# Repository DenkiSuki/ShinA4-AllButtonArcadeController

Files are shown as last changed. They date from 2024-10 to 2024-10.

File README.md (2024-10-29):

# ShinA4-AllButtonArcadeController
Repo for ShinA4, a custom 3DPrinted All Button Arcade Controller
ShinA4Hitbox-Layout
ShinA4Hitbox-2

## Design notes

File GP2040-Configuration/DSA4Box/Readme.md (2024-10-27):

# GP2040 Configuration for DSA4Box
3DPrinted Waveshare RP2040-Zero Based Arcade Controller
14+6Buttons
14RGBs LED for directional and action button 
USB Host
OLED

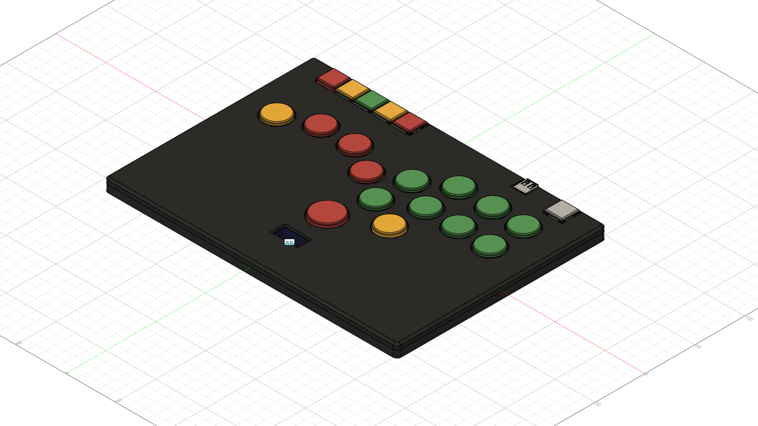
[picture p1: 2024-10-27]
Picture/ShinA4Hitbox-2.png

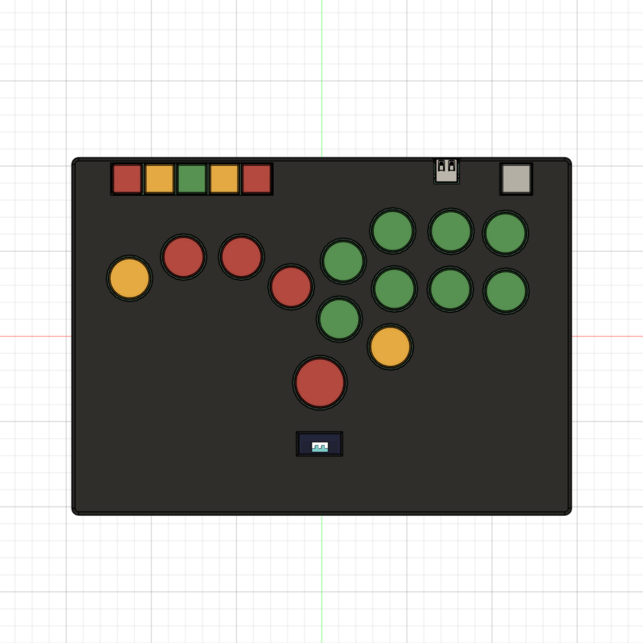
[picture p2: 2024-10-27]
Picture/ShinA4Hitbox-1.png

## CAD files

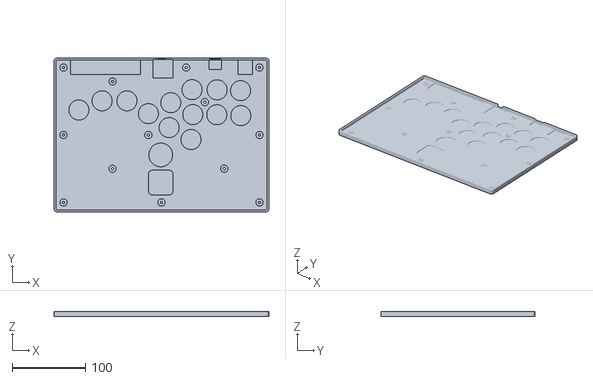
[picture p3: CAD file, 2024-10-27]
3DFile/BottomCase.stl
293.4 x 210.0 x 7.00

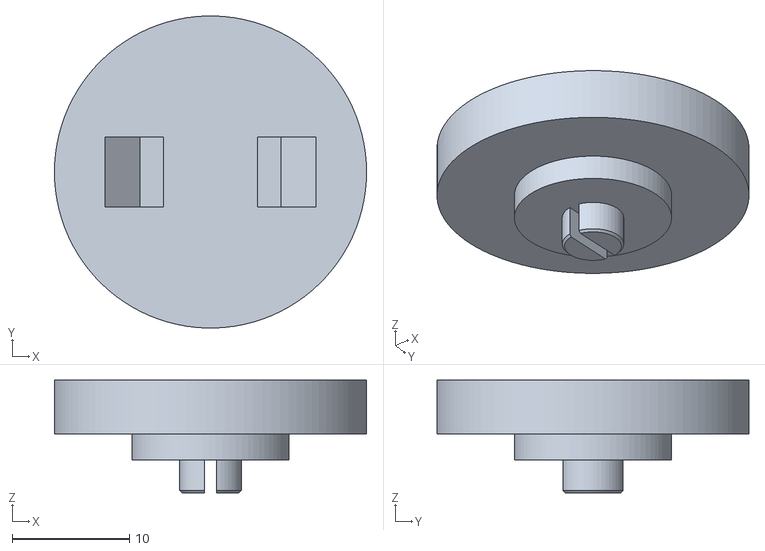
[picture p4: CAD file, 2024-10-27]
3DFile/HoleCap.stl
26.6 x 26.6 x 9.60

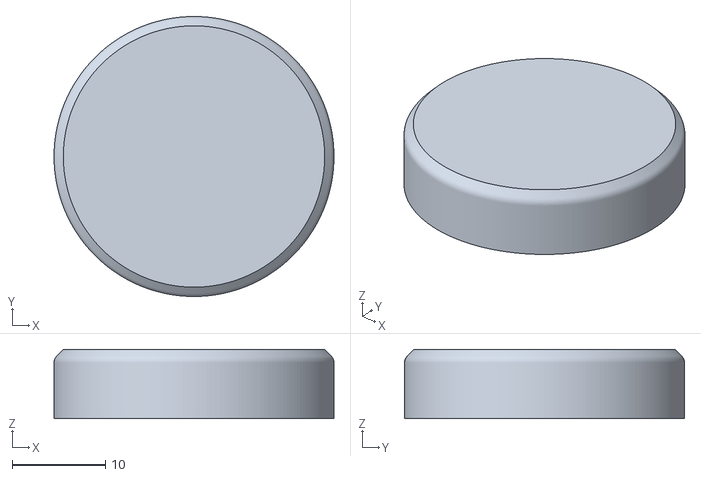
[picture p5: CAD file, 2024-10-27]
3DFile/30mmButtonCap.stl
30.0 x 30.0 x 7.40

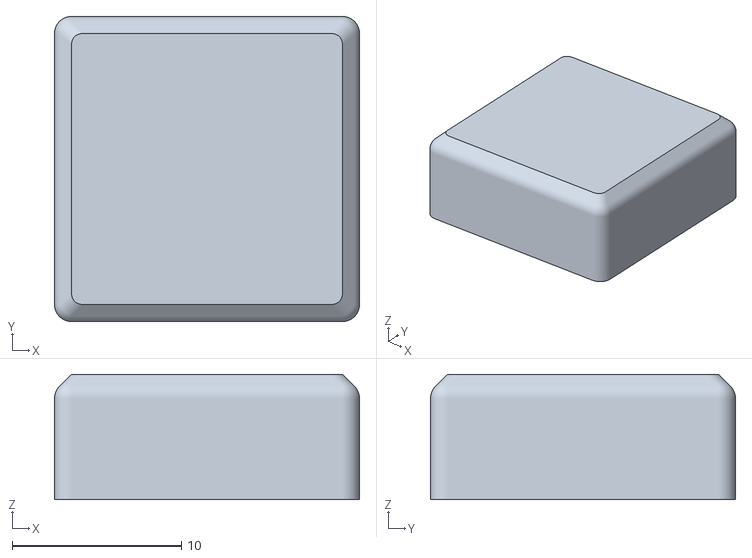
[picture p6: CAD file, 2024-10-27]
3DFile/MenuButtonCap.stl
18.0 x 18.0 x 7.40

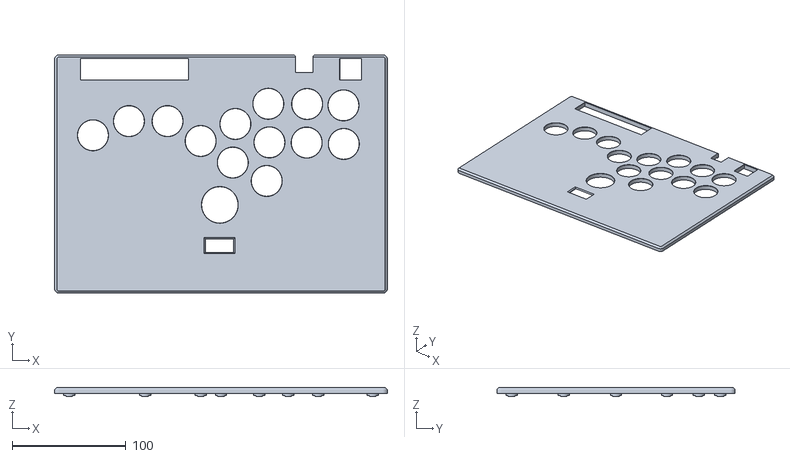
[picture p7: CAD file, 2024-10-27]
3DFile/TopCase.stl
293.4 x 210.0 x 8.20

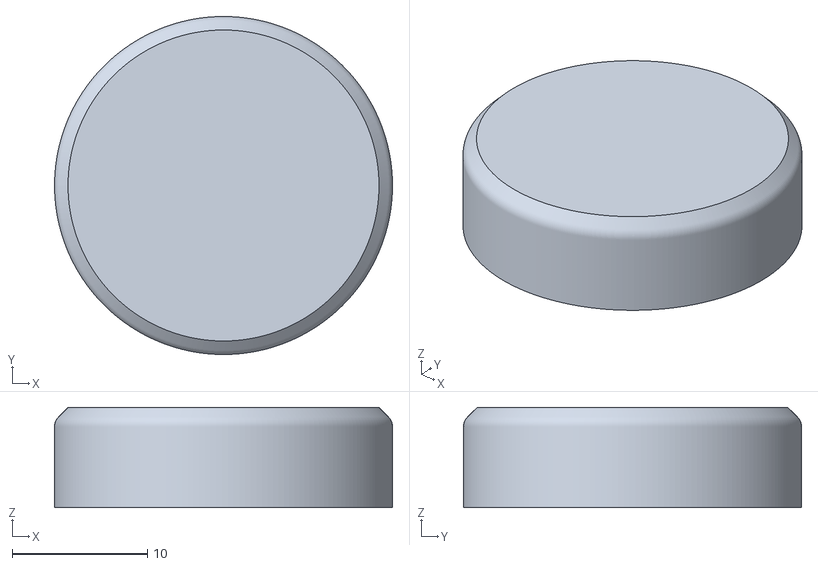
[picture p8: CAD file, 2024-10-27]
3DFile/25mmButtonCap.stl
25.0 x 25.0 x 7.40

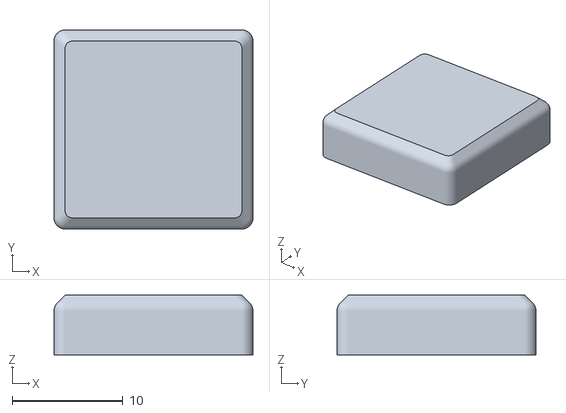
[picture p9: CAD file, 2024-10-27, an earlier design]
3DFile/Legacy/MenuButtonCap.stl
18.0 x 18.0 x 5.40

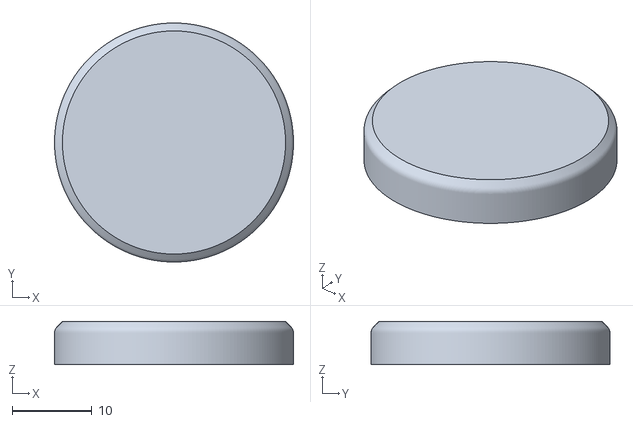
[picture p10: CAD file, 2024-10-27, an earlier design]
3DFile/Legacy/30mmButtonCap.stl
30.0 x 30.0 x 5.40

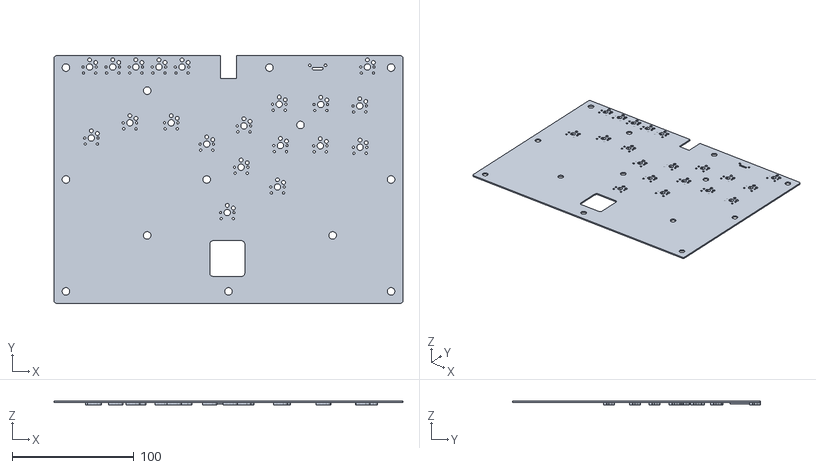
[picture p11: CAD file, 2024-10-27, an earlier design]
3DFile/Legacy/PseudoPCB.stl
287.0 x 203.6 x 3.40

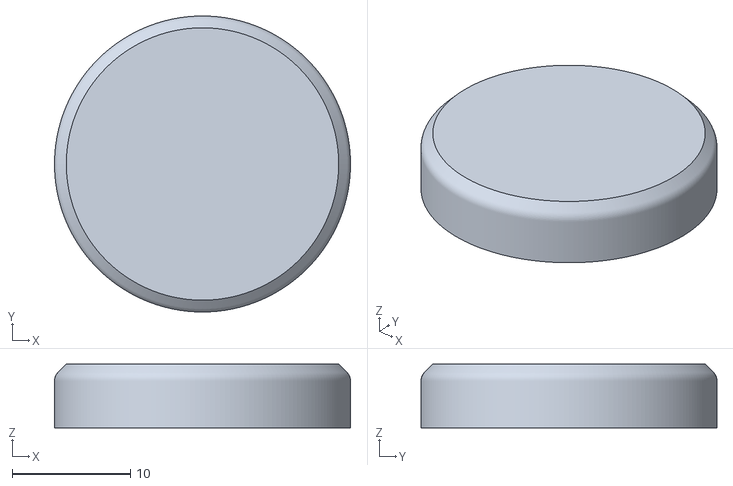
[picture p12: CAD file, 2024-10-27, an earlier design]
3DFile/Legacy/25mmButtonCap.stl
25.0 x 25.0 x 5.40

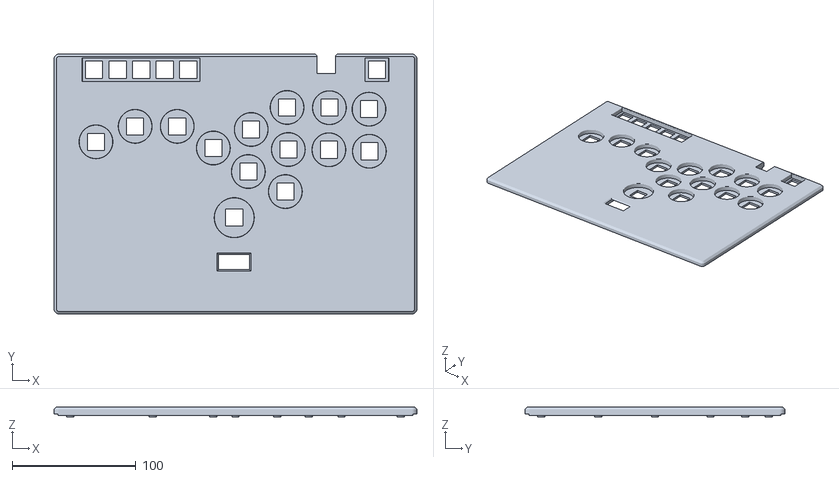
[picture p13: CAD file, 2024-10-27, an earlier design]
3DFile/Legacy/UpperBody.stl
293.4 x 210.0 x 8.20

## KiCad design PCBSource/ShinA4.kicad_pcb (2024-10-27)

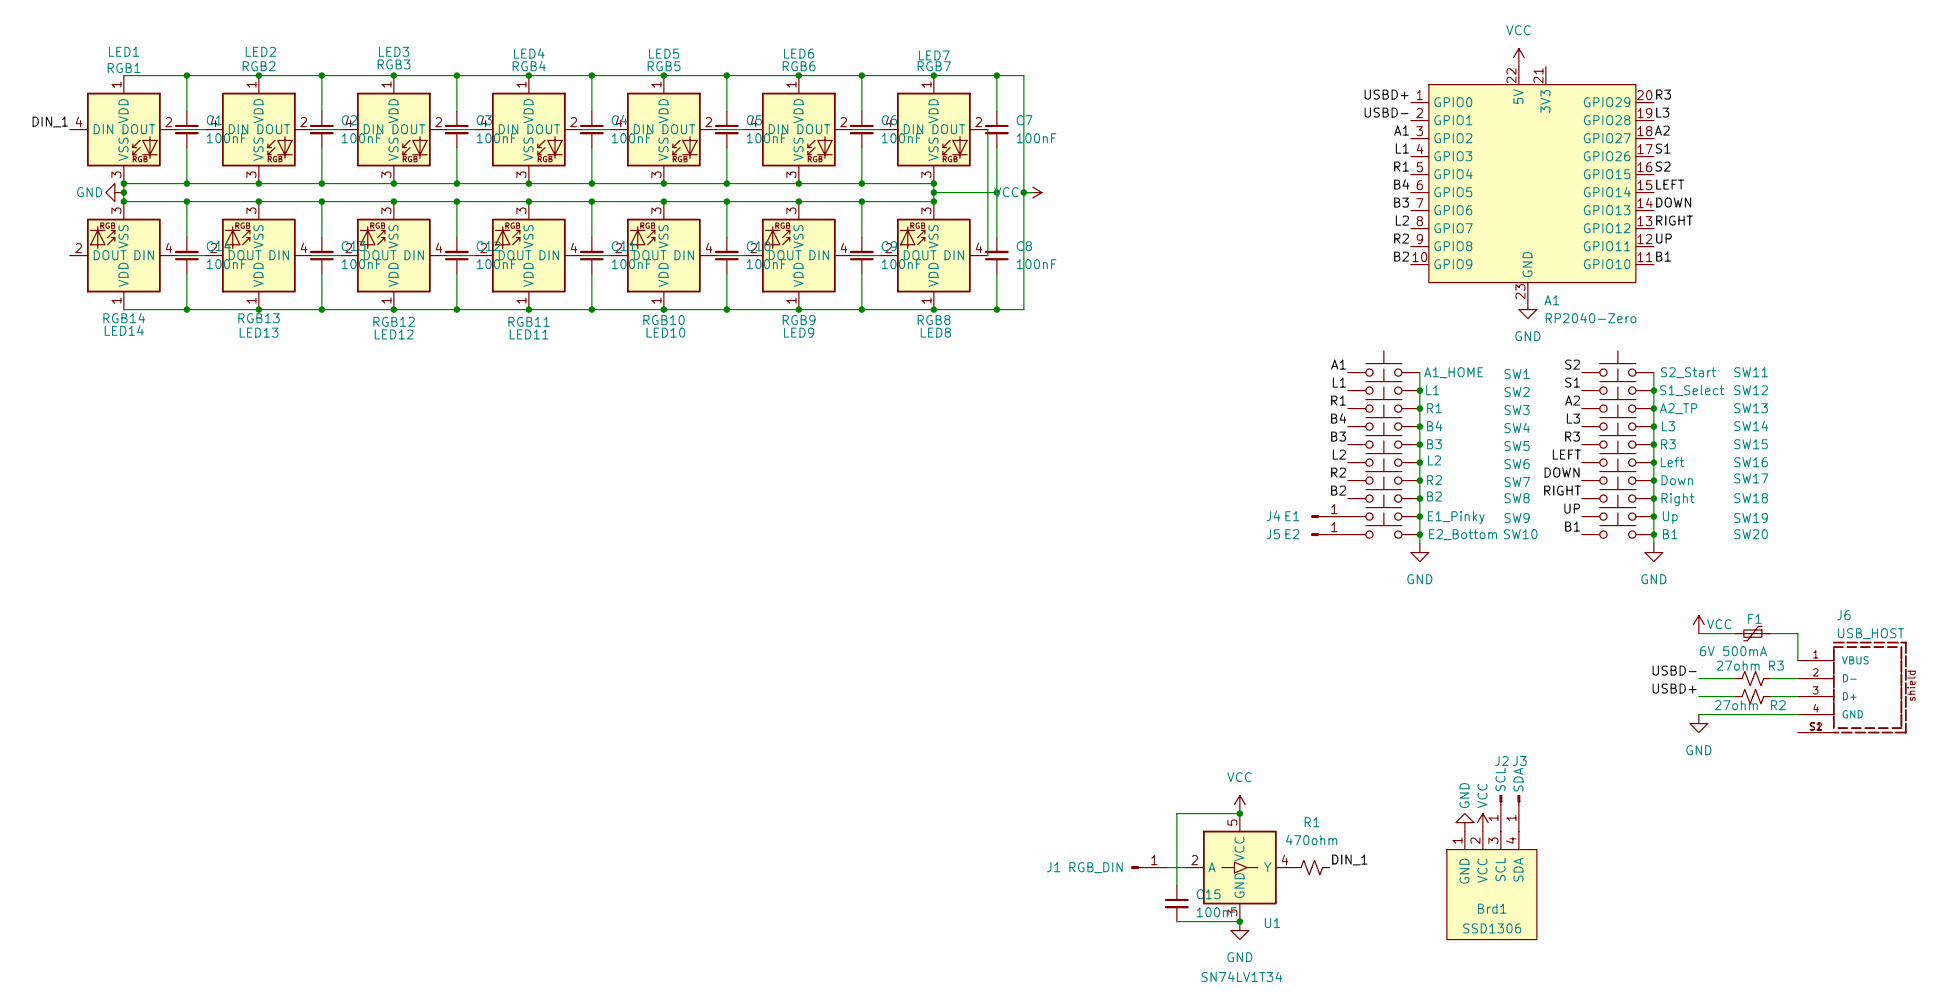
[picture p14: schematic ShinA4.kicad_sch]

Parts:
A1: RP2040-Zero; RP2040-Zero_BottomCu
Brd1: SSD1306; Display_128x64_096_I2C_Modified
C1, C2, C3, C4, C5, C6, C7, C8, C9, C10, C11, C12, C13, C14, C15: 100nF; C_0603_1608Metric_Pad1.08x0.95mm_HandSolder
F1: 6V 500mA; Fuse_0805_2012Metric_Pad1.15x1.40mm_HandSolder
J1: RGB_DIN; TestPoint_THTPad_D1.0mm_Drill0.5mm
J2: SCL; TestPoint_THTPad_D1.0mm_Drill0.5mm
J3: SDA; TestPoint_THTPad_D1.0mm_Drill0.5mm
J4: E1; TestPoint_THTPad_D1.0mm_Drill0.5mm
J5: E2; TestPoint_THTPad_D1.0mm_Drill0.5mm
J6: USB_HOST; 61400416021; PART-NUMBER 61400416021
LED1: RGB1; YS-SK6812MINI-E
LED2: RGB2; YS-SK6812MINI-E
LED3: RGB3; YS-SK6812MINI-E
LED4: RGB4; YS-SK6812MINI-E
LED5: RGB5; YS-SK6812MINI-E
LED6: RGB6; YS-SK6812MINI-E
LED7: RGB7; YS-SK6812MINI-E
LED8: RGB8; YS-SK6812MINI-E
LED9: RGB9; YS-SK6812MINI-E
LED10: RGB10; YS-SK6812MINI-E
LED11: RGB11; YS-SK6812MINI-E
LED12: RGB12; YS-SK6812MINI-E
LED13: RGB13; YS-SK6812MINI-E
LED14: RGB14; YS-SK6812MINI-E
R1: 470ohm; R_0603_1608Metric_Pad0.98x0.95mm_HandSolder
R2, R3: 27ohm; R_0603_1608Metric_Pad0.98x0.95mm_HandSolder
SW1: A1_HOME; Kailh_socket_PG1350_V1+2
SW2: L1; Kailh_socket_PG1350_V1+2
SW3: R1; Kailh_socket_PG1350_V1+2
SW4: B4; Kailh_socket_PG1350_V1+2
SW5: B3; Kailh_socket_PG1350_V1+2
SW6: L2; Kailh_socket_PG1350_V1+2
SW7: R2; Kailh_socket_PG1350_V1+2
SW8: B2; Kailh_socket_PG1350_V1+2
SW9: E1_Pinky; Kailh_socket_PG1350_V1+2
SW10: E2_Bottom; Kailh_socket_PG1350_V1+2
SW11: S2_Start; Kailh_socket_PG1350_V1+2
SW12: S1_Select; Kailh_socket_PG1350_V1+2
SW13: A2_TP; Kailh_socket_PG1350_V1+2
SW14: L3; Kailh_socket_PG1350_V1+2
SW15: R3; Kailh_socket_PG1350_V1+2
SW16: Left; Kailh_socket_PG1350_V1+2
SW17: Down; Kailh_socket_PG1350_V1+2
SW18: Right; Kailh_socket_PG1350_V1+2
SW19: Up; Kailh_socket_PG1350_V1+2
SW20: B1; Kailh_socket_PG1350_V1+2
U1: SN74LV1T34; SOT-23-5

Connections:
/A1: A1.3 (GPIO2), SW1.1
/A2: A1.18 (GPIO27), SW13.1
/B1: A1.11 (GPIO10), SW20.1
/B2: A1.10 (GPIO9), SW8.1
/B3: A1.7 (GPIO6), SW5.1
/B4: A1.6 (GPIO5), SW4.1
/DIN_1: LED1.4 (DIN), R1.2
/DOWN: A1.14 (GPIO13), SW17.1
/L1: A1.4 (GPIO3), SW2.1
/L2: A1.8 (GPIO7), SW6.1
/L3: A1.19 (GPIO28), SW14.1
/LEFT: A1.15 (GPIO14), SW16.1
/R1: A1.5 (GPIO4), SW3.1
/R2: A1.9 (GPIO8), SW7.1
/R3: A1.20 (GPIO29), SW15.1
/RIGHT: A1.13 (GPIO12), SW18.1
/S1: A1.17 (GPIO26), SW12.1
/S2: A1.16 (GPIO15), SW11.1
/UP: A1.12 (GPIO11), SW19.1
/USBD+: A1.1 (GPIO0), R2.2
/USBD-: A1.2 (GPIO1), R3.2
GND: A1.23 (GND), Brd1.1 (GND), C1.2, C2.2, C3.2, C4.2, C5.2, C6.2, C7.2, C8.2, C9.2, C10.2, C11.2, C12.2, C13.2, C14.2, C15.2, J6.4 (GND), LED1.3 (VSS), LED2.3 (VSS), LED3.3 (VSS), LED4.3 (VSS), LED5.3 (VSS), LED6.3 (VSS), LED7.3 (VSS), LED8.3 (VSS), LED9.3 (VSS), LED10.3 (VSS), LED11.3 (VSS), LED12.3 (VSS), LED13.3 (VSS), LED14.3 (VSS), SW1.2, SW2.2, SW3.2, SW4.2, SW5.2, SW6.2, SW7.2, SW8.2, SW9.2, SW10.2, SW11.2, SW12.2, SW13.2, SW14.2, SW15.2, SW16.2, SW17.2, SW18.2, SW19.2, SW20.2, U1.3 (GND)
unnamed: Brd1.3 (SCL), J2.1
unnamed: Brd1.4 (SDA), J3.1
unnamed: J1.1, U1.2 (A)
unnamed: J4.1, SW9.1
unnamed: J5.1, SW10.1
unnamed: J6.3 (D+), R2.1
unnamed: J6.2 (D-), R3.1
unnamed: J6.S1, J6.S2
unnamed: F1.1, J6.1 (VBUS)
unnamed: LED1.2 (DOUT), LED2.4 (DIN)
unnamed: LED2.2 (DOUT), LED3.4 (DIN)
unnamed: LED3.2 (DOUT), LED4.4 (DIN)
unnamed: LED4.2 (DOUT), LED5.4 (DIN)
unnamed: LED5.2 (DOUT), LED6.4 (DIN)
unnamed: LED6.2 (DOUT), LED7.4 (DIN)
unnamed: LED7.2 (DOUT), LED8.4 (DIN)
unnamed: LED8.2 (DOUT), LED9.4 (DIN)
unnamed: LED9.2 (DOUT), LED10.4 (DIN)
unnamed: LED10.2 (DOUT), LED11.4 (DIN)
unnamed: LED11.2 (DOUT), LED12.4 (DIN)
unnamed: LED12.2 (DOUT), LED13.4 (DIN)
unnamed: LED13.2 (DOUT), LED14.4 (DIN)
unnamed: R1.1, U1.4 (Y)
VCC: A1.22 (5V), Brd1.2 (VCC), C1.1, C2.1, C3.1, C4.1, C5.1, C6.1, C7.1, C8.1, C9.1, C10.1, C11.1, C12.1, C13.1, C14.1, C15.1, F1.2, LED1.1 (VDD), LED2.1 (VDD), LED3.1 (VDD), LED4.1 (VDD), LED5.1 (VDD), LED6.1 (VDD), LED7.1 (VDD), LED8.1 (VDD), LED9.1 (VDD), LED10.1 (VDD), LED11.1 (VDD), LED12.1 (VDD), LED13.1 (VDD), LED14.1 (VDD), U1.5 (VCC)

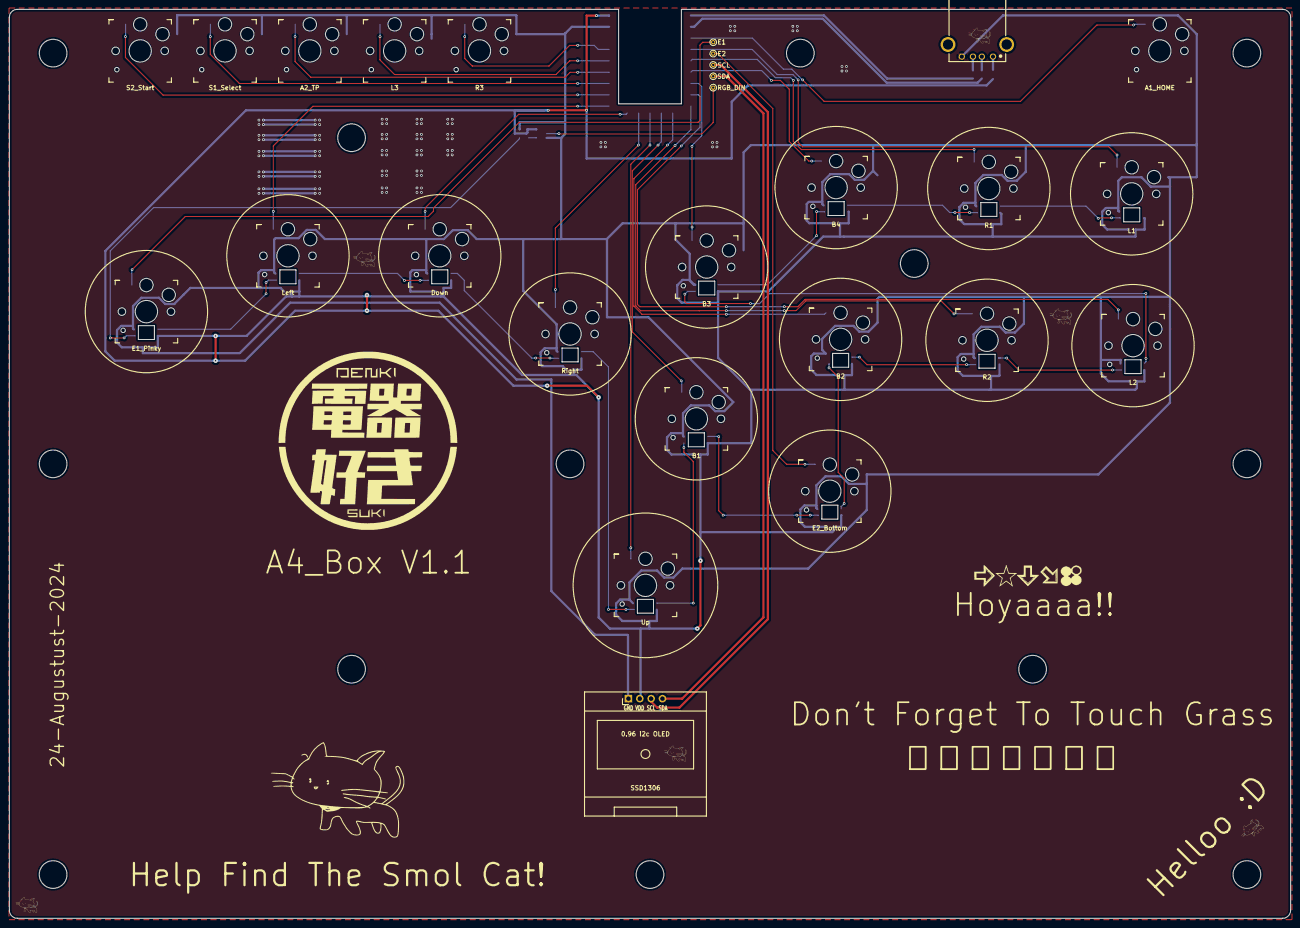
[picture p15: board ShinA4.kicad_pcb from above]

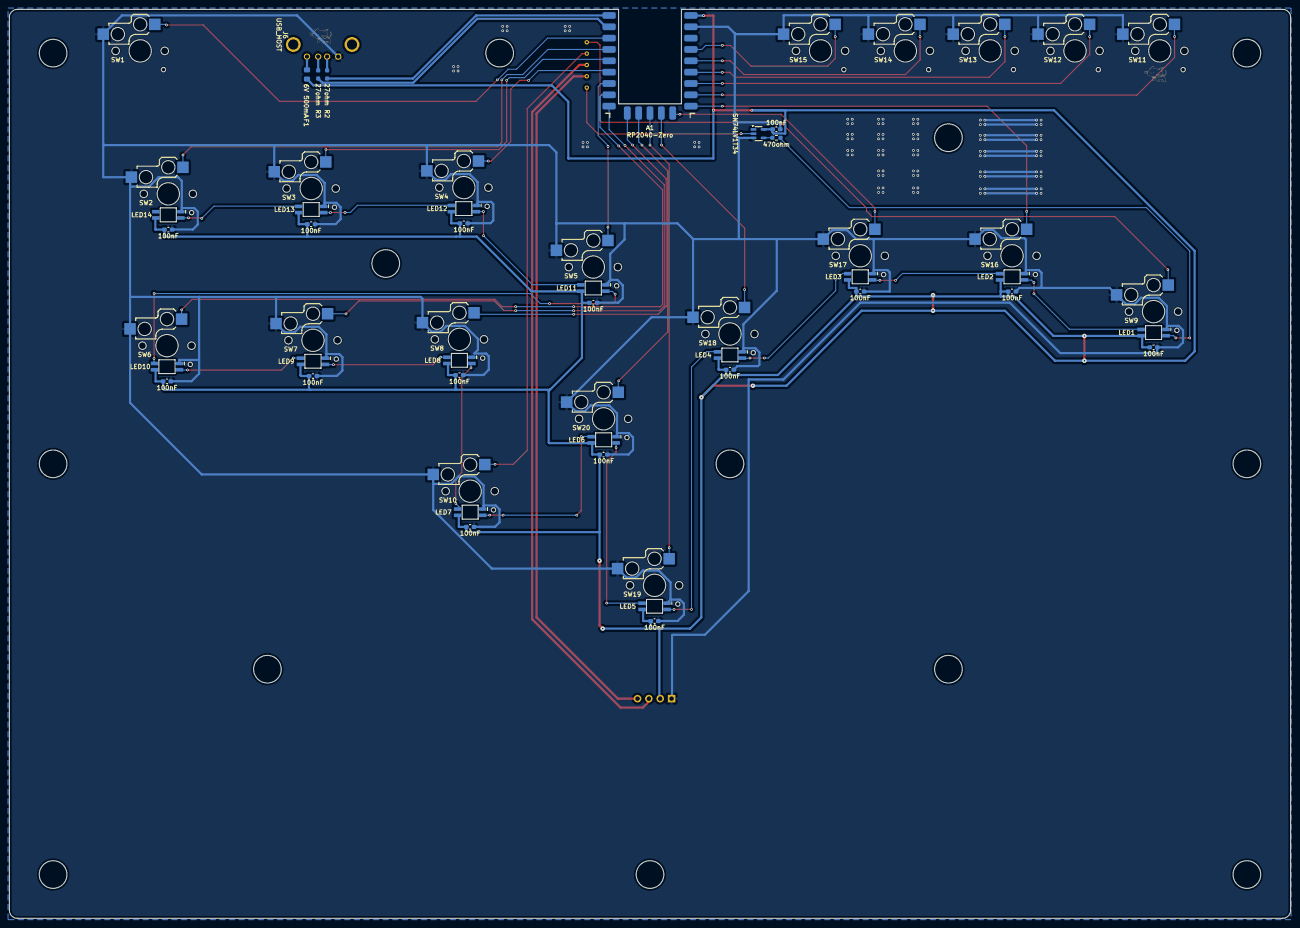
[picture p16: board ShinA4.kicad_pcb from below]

Board: 2 copper layers, 287.0 x 203.6 mm, 62 parts (34 on the bottom side), 46 nets.

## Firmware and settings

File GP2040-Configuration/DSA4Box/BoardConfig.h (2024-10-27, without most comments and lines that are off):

#define PICO_BOARD_CONFIG_H_
#include "enums.pb.h"
#include "class/hid/hid.h"
#define BOARD_CONFIG_LABEL "DenkiSuki A4 Sized Box Slim"
#define GPIO_PIN_11 GpioAction::BUTTON_PRESS_UP     // UP     | UP     | UP      | UP       | UP     | UP     |
#define GPIO_PIN_13 GpioAction::BUTTON_PRESS_DOWN   // DOWN   | DOWN   | DOWN    | DOWN     | DOWN   | DOWN   |
#define GPIO_PIN_12 GpioAction::BUTTON_PRESS_RIGHT  // RIGHT  | RIGHT  | RIGHT   | RIGHT    | RIGHT  | RIGHT  |
#define GPIO_PIN_14 GpioAction::BUTTON_PRESS_LEFT   // LEFT   | LEFT   | LEFT    | LEFT     | LEFT   | LEFT   |
#define GPIO_PIN_10 GpioAction::BUTTON_PRESS_B1     // B1     | A      | B       | Cross    | 2      | K1     |
#define GPIO_PIN_09 GpioAction::BUTTON_PRESS_B2     // B2     | B      | A       | Circle   | 3      | K2     |
#define GPIO_PIN_08 GpioAction::BUTTON_PRESS_R2     // R2     | RT     | ZR      | R2       | 8      | K3     |
#define GPIO_PIN_07 GpioAction::BUTTON_PRESS_L2     // L2     | LT     | ZL      | L2       | 7      | K4     |
#define GPIO_PIN_06 GpioAction::BUTTON_PRESS_B3     // B3     | X      | Y       | Square   | 1      | P1     |
#define GPIO_PIN_05 GpioAction::BUTTON_PRESS_B4     // B4     | Y      | X       | Triangle | 4      | P2     |
#define GPIO_PIN_04 GpioAction::BUTTON_PRESS_R1     // R1     | RB     | R       | R1       | 6      | P3     |
#define GPIO_PIN_03 GpioAction::BUTTON_PRESS_L1     // L1     | LB     | L       | L1       | 5      | P4     |
#define GPIO_PIN_26 GpioAction::BUTTON_PRESS_S1     // S1     | Back   | Minus   | Select   | 9      | Coin   |
#define GPIO_PIN_15 GpioAction::BUTTON_PRESS_S2     // S2     | Start  | Plus    | Start    | 10     | Start  |
#define GPIO_PIN_28 GpioAction::BUTTON_PRESS_L3     // L3     | LS     | LS      | L3       | 11     | LS     |
#define GPIO_PIN_29 GpioAction::BUTTON_PRESS_R3     // R3     | RS     | RS      | R3       | 12     | RS     |
#define GPIO_PIN_02 GpioAction::BUTTON_PRESS_A1     // A1     | Guide  | Home    | PS       | 13     | ~      |
#define GPIO_PIN_27 GpioAction::BUTTON_PRESS_A2     // A2     | ~      | Capture | ~        | 14     | ~      |
#define GPIO_PIN_24 GpioAction::BUTTON_PRESS_L3 // Left Pinky
#define GPIO_PIN_25 GpioAction::BUTTON_PRESS_R3
#define GPIO_PIN_20 GpioAction::ASSIGNED_TO_ADDON //OLEDSCL
#define GPIO_PIN_21 GpioAction::ASSIGNED_TO_ADDON //OLEDSDA
#define GPIO_PIN_00 GpioAction::ASSIGNED_TO_ADDON //USB-
#define GPIO_PIN_01 GpioAction::ASSIGNED_TO_ADDON //USB+
#define GPIO_PIN_19 GpioAction::ASSIGNED_TO_ADDON //RGB_DATA
#define KEY_DPAD_UP     HID_KEY_ARROW_UP      // UP     | UP     | UP      | UP       | UP     | UP     |
#define KEY_DPAD_DOWN   HID_KEY_ARROW_DOWN    // DOWN   | DOWN   | DOWN    | DOWN     | DOWN   | DOWN   |
#define KEY_DPAD_RIGHT  HID_KEY_ARROW_RIGHT   // RIGHT  | RIGHT  | RIGHT   | RIGHT    | RIGHT  | RIGHT  |
#define KEY_DPAD_LEFT   HID_KEY_ARROW_LEFT    // LEFT   | LEFT   | LEFT    | LEFT     | LEFT   | LEFT   |
#define KEY_BUTTON_B1   HID_KEY_SHIFT_LEFT    // B1     | A      | B       | Cross    | 2      | K1     |
#define KEY_BUTTON_B2   HID_KEY_Z             // B2     | B      | A       | Circle   | 3      | K2     |
#define KEY_BUTTON_R2   HID_KEY_X             // R2     | RT     | ZR      | R2       | 8      | K3     |
#define KEY_BUTTON_L2   HID_KEY_V             // L2     | LT     | ZL      | L2       | 7      | K4     |
#define KEY_BUTTON_B3   HID_KEY_CONTROL_LEFT  // B3     | X      | Y       | Square   | 1      | P1     |
#define KEY_BUTTON_B4   HID_KEY_ALT_LEFT      // B4     | Y      | X       | Triangle | 4      | P2     |
#define KEY_BUTTON_R1   HID_KEY_SPACE         // R1     | RB     | R       | R1       | 6      | P3     |
#define KEY_BUTTON_L1   HID_KEY_C             // L1     | LB     | L       | L1       | 5      | P4     |
#define KEY_BUTTON_S1   HID_KEY_5             // S1     | Back   | Minus   | Select   | 9      | Coin   |
#define KEY_BUTTON_S2   HID_KEY_1             // S2     | Start  | Plus    | Start    | 10     | Start  |
#define KEY_BUTTON_L3   HID_KEY_EQUAL         // L3     | LS     | LS      | L3       | 11     | LS     |
#define KEY_BUTTON_R3   HID_KEY_MINUS         // R3     | RS     | RS      | R3       | 12     | RS     |
#define KEY_BUTTON_A1   HID_KEY_9             // A1     | Guide  | Home    | PS       | 13     | ~      |
#define KEY_BUTTON_A2   HID_KEY_F2            // A2     | ~      | Capture | ~        | 14     | ~      |
#define KEY_BUTTON_FN   -1                    // Hotkey Function                                        |
#define USB_PERIPHERAL_ENABLED 1
#define USB_PERIPHERAL_PIN_DPLUS 00
#define USB_PERIPHERAL_PIN_ORDER 0 //D+ = 00 D- = 01
#define USB_PERIPHERAL_PIN_5V -1
#define KEYBOARD_HOST_ENABLED 1
#define DEFAULT_INPUT_MODE_B1 INPUT_MODE_SWITCH
#define DEFAULT_INPUT_MODE_B2 INPUT_MODE_XINPUT
#define DEFAULT_INPUT_MODE_B3 INPUT_MODE_PS3
#define DEFAULT_INPUT_MODE_B4 INPUT_MODE_PS4
#define DEFAULT_INPUT_MODE_R1 INPUT_MODE_XBONE
#define DEFAULT_INPUT_MODE_R2 INPUT_MODE_KEYBOARD
#define DEFAULT_INPUT_MODE_L1 INPUT_MODE_PS5
#define DEFAULT_INPUT_MODE_L2 INPUT_MODE_GENERIC
#define DEFAULT_PS4AUTHENTICATION_TYPE INPUT_MODE_AUTH_TYPE_USB
#define DEFAULT_PS5AUTHENTICATION_TYPE INPUT_MODE_AUTH_TYPE_USB
#define BOARD_LEDS_PIN 19
#define LED_BRIGHTNESS_MAXIMUM 50
#define LED_BRIGHTNESS_STEPS 5
#define LEDS_BASE_ANIMATION_INDEX 1
#define LEDS_PER_PIXEL 1
#define LEDS_BUTTON_R3   0
#define LEDS_DPAD_LEFT   1
#define LEDS_DPAD_DOWN   2
#define LEDS_DPAD_RIGHT  3
#define LEDS_DPAD_UP     4
#define LEDS_BUTTON_B1   5
#define LEDS_BUTTON_L3   6
#define LEDS_BUTTON_B2   7
#define LEDS_BUTTON_R2   8
#define LEDS_BUTTON_L2   9
#define LEDS_BUTTON_B3   10
#define LEDS_BUTTON_B4   11
#define LEDS_BUTTON_R1   12
#define LEDS_BUTTON_L1   13
#define HAS_I2C_DISPLAY 1
#define I2C0_ENABLED 1
#define I2C0_PIN_SDA 20
#define I2C0_PIN_SCL 21
#define DISPLAY_I2C_BLOCK i2c0
#define I2C_SPEED 400000
#define DISPLAY_I2C_ADDR 0x3c
#define DISPLAY_FLIP 0
#define DISPLAY_INVERT 0
#define SPLASH_MODE SPLASH_MODE_STATIC
#define SPLASH_DURATION 3000
#define BUTTON_LAYOUT BUTTON_LAYOUT_BOARD_DEFINED_A
#define BUTTON_LAYOUT_RIGHT BUTTON_LAYOUT_BOARD_DEFINED_B
#define DEFAULT_BOARD_LAYOUT_A {\
    {GP_ELEMENT_PIN_BUTTON, {26, 20,  7,  7, 1, 1, 14,  GP_SHAPE_ELLIPSE}},\
    {GP_ELEMENT_PIN_BUTTON, {42, 20,  7,  7, 1, 1, 13,  GP_SHAPE_ELLIPSE}},\
    {GP_ELEMENT_PIN_BUTTON, {56, 28,  7,  7, 1, 1, 12, GP_SHAPE_ELLIPSE}},\
    {GP_ELEMENT_PIN_BUTTON, {62, 50,  7,  7, 1, 1, 11,    GP_SHAPE_ELLIPSE}},\
    {GP_ELEMENT_PIN_BUTTON, {10, 22,  7,  7, 1, 1, 25,    GP_SHAPE_ELLIPSE}},\
    {GP_ELEMENT_PIN_BUTTON, {84, 50,  7,  7, 1, 1, 24,    GP_SHAPE_ELLIPSE}}\
}
#define DEFAULT_BOARD_LAYOUT_B {\
    {GP_ELEMENT_PIN_BUTTON, { 70, 20, 7, 7, 1, 1, 6,     GP_SHAPE_ELLIPSE}},\
    {GP_ELEMENT_PIN_BUTTON, { 86, 16, 7, 7, 1, 1, 5,     GP_SHAPE_ELLIPSE}},\
    {GP_ELEMENT_PIN_BUTTON, {102, 16, 7, 7, 1, 1, 4,    GP_SHAPE_ELLIPSE}},\
    {GP_ELEMENT_PIN_BUTTON, {118, 20, 7, 7, 1, 1, 3,    GP_SHAPE_ELLIPSE}},\
    {GP_ELEMENT_PIN_BUTTON, { 70, 36, 7, 7, 1, 1, 10,     GP_SHAPE_ELLIPSE}},\
    {GP_ELEMENT_PIN_BUTTON, { 86, 32, 7, 7, 1, 1, 9,     GP_SHAPE_ELLIPSE}},\
    {GP_ELEMENT_PIN_BUTTON, {102, 32, 7, 7, 1, 1, 8,    GP_SHAPE_ELLIPSE}},\
    {GP_ELEMENT_PIN_BUTTON, {118, 36, 7, 7, 1, 1, 7,    GP_SHAPE_ELLIPSE}}\
}

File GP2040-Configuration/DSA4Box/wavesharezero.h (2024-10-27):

/*
 * Copyright (c) 2020 Raspberry Pi (Trading) Ltd.
 *
 * SPDX-License-Identifier: BSD-3-Clause
 */

// -----------------------------------------------------
// NOTE: THIS HEADER IS ALSO INCLUDED BY ASSEMBLER SO
//       SHOULD ONLY CONSIST OF PREPROCESSOR DIRECTIVES
// -----------------------------------------------------


#ifndef _BOARDS_WAVESHAREZERO_H
#define _BOARDS_WAVESHAREZERO_H

// For board detection
#define WAVESHAREZERO

//For crappy crystal
#ifndef PICO_XOSC_STARTUP_DELAY_MULTIPLIER
#define PICO_XOSC_STARTUP_DELAY_MULTIPLIER 64
#endif

// --- UART ---
#ifndef PICO_DEFAULT_UART
#define PICO_DEFAULT_UART 0
#endif
#ifndef PICO_DEFAULT_UART_TX_PIN
#define PICO_DEFAULT_UART_TX_PIN 0
#endif
#ifndef PICO_DEFAULT_UART_RX_PIN
#define PICO_DEFAULT_UART_RX_PIN 1
#endif

// --- WS2812 ---
//#ifndef PICO_DEFAULT_WS2812_PIN
//#define PICO_DEFAULT_WS2812_PIN 16
//#endif

// --- I2C ---
#ifndef PICO_DEFAULT_I2C
#define PICO_DEFAULT_I2C 0
#endif
#ifndef PICO_DEFAULT_I2C_SDA_PIN
#define PICO_DEFAULT_I2C_SDA_PIN 20
#endif
#ifndef PICO_DEFAULT_I2C_SCL_PIN
#define PICO_DEFAULT_I2C_SCL_PIN 21
#endif

// --- SPI ---
#ifndef PICO_DEFAULT_SPI
#define PICO_DEFAULT_SPI 0
#endif
#ifndef PICO_DEFAULT_SPI_SCK_PIN
#define PICO_DEFAULT_SPI_SCK_PIN 18
#endif
#ifndef PICO_DEFAULT_SPI_TX_PIN
#define PICO_DEFAULT_SPI_TX_PIN 19
#endif
#ifndef PICO_DEFAULT_SPI_RX_PIN
#define PICO_DEFAULT_SPI_RX_PIN 16
#endif
#ifndef PICO_DEFAULT_SPI_CSN_PIN
#define PICO_DEFAULT_SPI_CSN_PIN 17
#endif

// --- FLASH ---

#define PICO_BOOT_STAGE2_CHOOSE_W25Q080 1

#ifndef PICO_FLASH_SPI_CLKDIV
#define PICO_FLASH_SPI_CLKDIV 2
#endif

#ifndef PICO_FLASH_SIZE_BYTES
#define PICO_FLASH_SIZE_BYTES (2 * 1024 * 1024)
#endif

// Drive high to force power supply into PWM mode (lower ripple on 3V3 at light loads)
#define PICO_SMPS_MODE_PIN 23

#ifndef PICO_RP2040_B0_SUPPORTED
#define PICO_RP2040_B0_SUPPORTED 1
#endif

#endif

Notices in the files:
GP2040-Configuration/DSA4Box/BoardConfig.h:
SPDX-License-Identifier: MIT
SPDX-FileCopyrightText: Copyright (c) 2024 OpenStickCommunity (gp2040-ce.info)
